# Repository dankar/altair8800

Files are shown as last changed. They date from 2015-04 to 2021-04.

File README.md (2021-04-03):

altair8800
==========

What is this?
-------------

What started as a Intel 8080 emulator turned into a Altair 8800 emulator with associated hardware for a front panel.

An updated version of this project is available at https://github.com/dankar/nanoaltair8800

Building
--------

The build for Arduino Uno is the most up to date. It should work to run "./build" and then "make && upload" in the arduino folder to compile and program.

arduino-mk is used by the makefile.

The code will look for certain files on the SD card. "88dskrom.bin" is a disk bootloader which will be loaded to offset 0xff00 in memory. "disk1.bin" and "disk2.bin" will be used by the 88-DCDD emulator and will act as disk 1 and disk 2 respectively.

Completeness
------------

Passes Kelly Smith test and cputest.com. Runs CP/M and all kinds of BASIC I could find. Altair DOS not working for some reason (complains about insufficient memory). Support for 88-DCDD. No tape or cassette.

There are probably still a few bugs that needs ironing out.

The performance is pretty poor. The emulator runs a couple of times slower than an original Altair 8800 which is a bit disappointing. It's of course also possible porting it to a faster MCU with more memory. Higher optimization levels will cause the code not to fit on an atmega328 but there are still code optimizations to be done. It is currently not possible to stop execution once started with the RUN/STOP switch. It's way too slow to check the front panel switches for each main loop.

Hardware
--------

A front panel has been designed and is available as a KiCad project under the PCB folder. The front panel is basically a bunch of shift registers for input from the switches and output to the LEDs, as well as a 23LC1024 SPI SRAM chip for memory and a MicroSD reader. Everything is attached on the SPI bus to the Arduino.

Known bugs
----------

The current hardware implementation has a bug in the MicroSD card holder-area. The pins are connected as they should be for a regular size SD card and not a MicroSD. If you want to use the panel with a MicroSD card you need to fix this.

Raspberry Pi
------------

The current code in the repo now supports running on Raspberry Pi instead of Arduino. This means that the MicroSD slot is not necessary any more, as well as the SRAM chip. The code runs faster on a Raspberry Pi as well. I would recommend this route for anyone interested in their own panel.

Todo
----

* Separate the Intel 8080 emulator and the Altair 8800 hardware emulation. E.g. make the port IO more abstract instead of Altair 8800 specific.
* Optimizations
* RUN/STOP switch enabled when running

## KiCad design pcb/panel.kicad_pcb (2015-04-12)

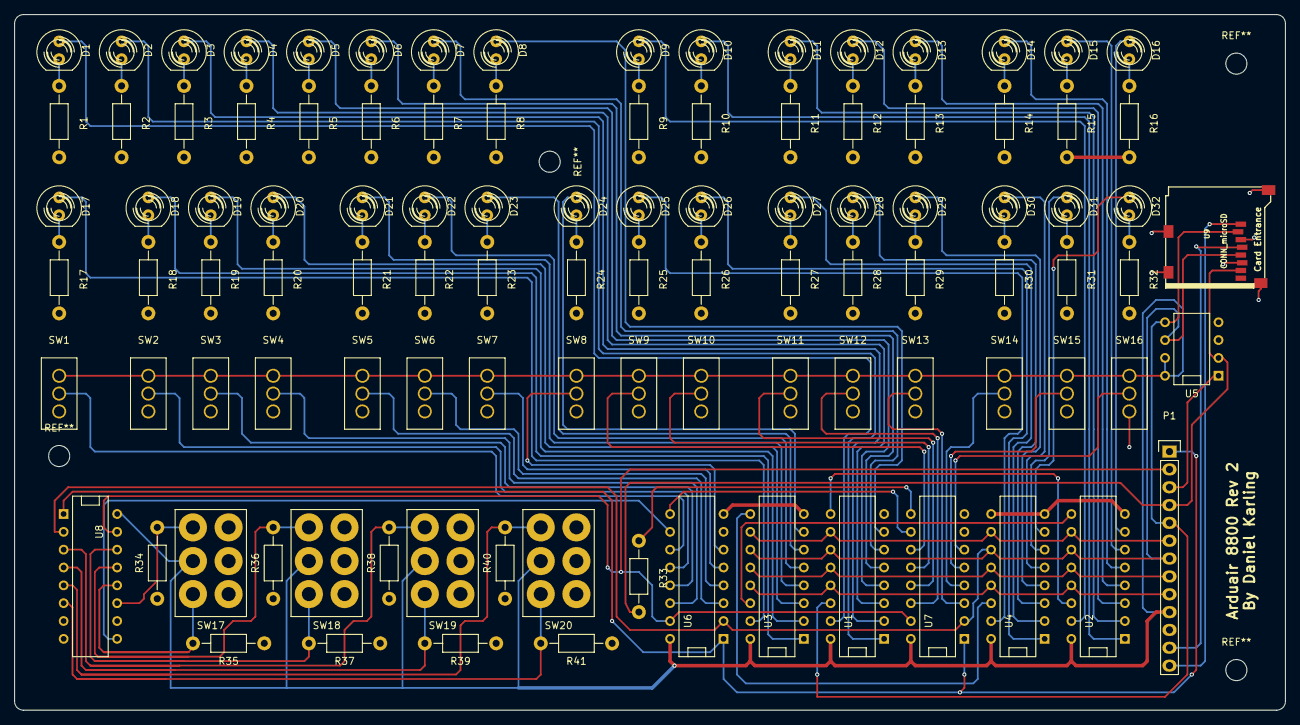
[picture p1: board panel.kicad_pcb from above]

Board: 2 copper layers, 181.0 x 99.1 mm, 103 parts (0 on the bottom side), 107 nets.

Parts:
D1, D2, D3, D4, D5, D6, D7, D8, D9, D10, D11, D12, D13, D14, D15, D16, D17, D18, D19, D20, D21, D22, D23, D24, D25, D26, D27, D28, D29, D30, D31, D32: LED; LED-5MM
P1: CONN_01X09; Pin_Header_Straight_1x13
R1, R2, R3, R4, R5, R6, R7, R8, R9, R10, R11, R12, R13, R14, R15, R16, R17, R18, R19, R20, R21, R22, R23, R24, R25, R26, R27, R28, R29, R30, R31, R32, R33: 220R; Resistor_Horizontal_RM10mm
R34, R35, R36, R37, R38, R39, R40, R41: 10K; Resistor_Horizontal_RM10mm
SW1, SW2, SW3, SW4, SW5, SW6, SW7, SW8, SW9, SW10, SW11, SW12, SW13, SW14, SW15, SW16: SWITCH_INV; SwitchOnOn
SW17, SW18, SW19, SW20: SP3T; SwitchOnOffOn
U1, U2, U3, U4: 74HC595; DIP-16__300
U5: 23LC1024; DIP-8__300
U6, U7, U8: 74LS165; DIP-16__300
U9: CONN_microSD; Memory_Card_microSD_3M_290805

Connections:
/CLK: P1.7, U1.11, U2.11, U3.11, U4.11, U5.6, U6.2, U7.2, U8.2, U9.5
/LA1: D1.1, U1.15
/LA2: D2.1, U1.1
/LA3: D3.1, U1.2
/LA4: D4.1, U1.3
/LA5: D5.1, U1.4
/LA6: D6.1, U1.5
/LA7: D7.1, U1.6
/LA8: D8.1, U1.7
/LB1: D9.1, U2.15
/LB2: D10.1, U2.1
/LB3: D11.1, U2.2
/LB4: D12.1, U2.3
/LB5: D13.1, U2.4
/LB6: D14.1, U2.5
/LB7: D15.1, U2.6
/LB8: D16.1, U2.7
/LC1: D17.1, U3.15
/LC2: D18.1, U3.1
/LC3: D19.1, U3.2
/LC4: D20.1, U3.3
/LC5: D21.1, U3.4
/LC6: D22.1, U3.5
/LC7: D23.1, U3.6
/LC8: D24.1, U3.7
/LD1: D25.1, U4.15
/LD2: D26.1, U4.1
/LD3: D27.1, U4.2
/LD4: D28.1, U4.3
/LD5: D29.1, U4.4
/LD6: D30.1, U4.5
/LD7: D31.1, U4.6
/LD8: D32.1, U4.7
/LEDSTORE: P1.8, U1.12, U2.12, U3.12, U4.12
/MEM_CS: P1.3, U5.1
/MISO: P1.4, R33.2, U5.2, U9.7
/MOSI: P1.5, U1.14, U5.5, U9.2
/MR: P1.6, U1.10, U2.10, U3.10, U4.10
/OE: P1.9, U1.13, U2.13, U3.13, U4.13
/SD_SC: P1.13, U9.1
/SWA1: SW1.2, U6.11
/SWA2: SW2.2, U6.12
/SWA3: SW3.2, U6.13
/SWA4: SW4.2, U6.14
/SWA5: SW5.2, U6.3
/SWA6: SW6.2, U6.4
/SWA7: SW7.2, U6.5
/SWA8: SW8.2, U6.6
/SWB1: SW9.2, U7.11
/SWB2: SW10.2, U7.12
/SWB3: SW11.2, U7.13
/SWB4: SW12.2, U7.14
/SWB5: SW13.2, U7.3
/SWB6: SW14.2, U7.4
/SWB7: SW15.2, U7.5
/SWB8: SW16.2, U7.6
/SWC1: R34.1, SW17.1, U8.11
/SWC2: R35.1, SW17.4, U8.12
/SWC3: R36.1, SW18.1, U8.13
/SWC4: R37.1, SW18.4, U8.14
/SWC5: R38.1, SW19.1, U8.3
/SWC6: R39.1, SW19.4, U8.4
/SWC7: R40.1, SW20.1, U8.5
/SWC8: R41.1, SW20.4, U8.6
/SWITCH_CS: P1.2, U6.15, U7.15, U8.15
/SWITCH_LOAD: P1.1, U6.1, U7.1, U8.1
/VCC33: P1.12, U9.4
GND: P1.11, R1.2, R2.2, R3.2, R4.2, R5.2, R6.2, R7.2, R8.2, R9.2, R10.2, R11.2, R12.2, R13.2, R14.2, R15.2, R16.2, R17.2, R18.2, R19.2, R20.2, R21.2, R22.2, R23.2, R24.2, R25.2, R26.2, R27.2, R28.2, R29.2, R30.2, R31.2, R32.2, R34.2, R35.2, R36.2, R37.2, R38.2, R39.2, R40.2, R41.2, SW1.1, SW2.1, SW3.1, SW4.1, SW5.1, SW6.1, SW7.1, SW8.1, SW9.1, SW10.1, SW11.1, SW12.1, SW13.1, SW14.1, SW15.1, SW16.1, U1.8, U2.8, U3.8, U4.8, U4.9, U5.3, U5.4, U6.7, U6.8, U7.7, U7.8, U8.7, U8.8, U8.10, U9.3, U9.6, U9.9
unnamed: D1.2, R1.1
unnamed: D2.2, R2.1
unnamed: D3.2, R3.1
unnamed: D4.2, R4.1
unnamed: D5.2, R5.1
unnamed: D6.2, R6.1
unnamed: D7.2, R7.1
unnamed: D8.2, R8.1
unnamed: D9.2, R9.1
unnamed: D10.2, R10.1
unnamed: D11.2, R11.1
unnamed: D12.2, R12.1
unnamed: D13.2, R13.1
unnamed: D14.2, R14.1
unnamed: D15.2, R15.1
unnamed: D16.2, R16.1
unnamed: D17.2, R17.1
unnamed: D18.2, R18.1
unnamed: D19.2, R19.1
unnamed: D20.2, R20.1
unnamed: D21.2, R21.1
unnamed: D22.2, R22.1
unnamed: D23.2, R23.1
unnamed: D24.2, R24.1
unnamed: D25.2, R25.1
unnamed: D26.2, R26.1
unnamed: D27.2, R27.1
unnamed: D28.2, R28.1
unnamed: D29.2, R29.1
unnamed: D30.2, R30.1
unnamed: D31.2, R31.1
unnamed: D32.2, R32.1
unnamed: R33.1, U7.9
unnamed: U1.9, U2.14
unnamed: U2.9, U3.14
unnamed: U3.9, U4.14
unnamed: U6.9, U7.10
unnamed: U6.10, U8.9
VCC: P1.10, SW1.3, SW2.3, SW3.3, SW4.3, SW5.3, SW6.3, SW7.3, SW8.3, SW9.3, SW10.3, SW11.3, SW12.3, SW13.3, SW14.3, SW15.3, SW16.3, SW17.3, SW18.3, SW19.3, SW20.3, U1.16, U2.16, U3.16, U4.16, U5.7, U5.8, U6.16, U7.16, U8.16

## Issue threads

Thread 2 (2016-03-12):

Wiring for MicroSD connector is incorrect

dankar, 2016-03-12:
The MicroSD slot is wired to regular SD card. This is not correct and should be fixed.

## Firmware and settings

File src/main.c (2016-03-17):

#include <stdio.h>
#include <stdlib.h>
#include "intel8080.h"
#include "88dcdd.h"
#ifdef WIN32
	#include <Windows.h>
	#include <WinSock.h>
#else
	// socket
	#include <sys/types.h>
	#include <sys/socket.h>
	#include <netinet/in.h>
	#include <netinet/ip.h>
	#include <sys/ioctl.h>
	#include <fcntl.h>

	// strcat
	#include <string.h>
	#include "pi_panel.h"
	#include <wiringPi.h>
#endif

int sock;
int client_sock;

void dump_regs(intel8080_t *cpu)
{
	printf("%04x\t%02x\t%04x\tC: %02x\tD: %02x\tE: %02x\n", cpu->address_bus, cpu->data_bus, cpu->registers.pc, cpu->registers.c, cpu->registers.d, cpu->registers.e);
}

#ifdef WIN32
uint8_t key_states[256];

uint8_t get_key(uint8_t code)
{
	uint8_t ret_val = 0;

	if(GetAsyncKeyState(code))
	{
		if(!key_states[code])
			ret_val = 1;

		key_states[code] = 1;
	}
	else
	{
		key_states[code] = 0;
	}

	return ret_val;
}
#endif

uint8_t term_in()
{
	uint8_t b;

	if(recv(client_sock, (char*)&b, 1, 0) != 1)
	{
		return 0;
	}
	else
	{
		return b;
	}
}

void term_out(uint8_t b)
{
	b = b & 0x7f;
	send(client_sock, (char*)&b, 1, 0);
}

uint8_t memory[64*1024];
uint8_t cmd_switches;
uint16_t bus_switches;

void load_file(intel8080_t *cpu)
{
	size_t size = 0;
	FILE* fp = fopen("software/input.com", "rb");

	fseek(fp, 0, SEEK_END);
	size = ftell(fp);
	fseek(fp, 0, SEEK_SET);
	fread(&memory[0x100], 1, size, fp);
	fclose(fp);
}

const char *byte_to_binary(int x)
{
	int z;
    static char b[9];
    b[0] = '\0';

    for (z = 128; z > 0; z >>= 1)
    {
        strcat(b, ((x & z) == z) ? "1" : "0");
    }

    return b;
}


void load_mem_file(const char* filename, size_t offset)
{
	size_t size;
	FILE* fp = fopen(filename, "rb");
	fseek(fp, 0, SEEK_END);
	size = ftell(fp);
	fseek(fp, 0, SEEK_SET);
	fread(&memory[offset], 1, size, fp);
	fclose(fp);
}

uint8_t sense()
{
	return bus_switches >> 8;
}

void load_memory()
{
        load_mem_file("software/ROMs/DBL.bin", 0xff00);
        load_mem_file("software/ROMs/8K Basic/8kBas_e0.bin", 0xe000);
        load_mem_file("software/ROMs/8K Basic/8kBas_e8.bin", 0xe800);
        load_mem_file("software/ROMs/8K Basic/8kBas_f0.bin", 0xf000);
        load_mem_file("software/ROMs/8K Basic/8kBas_f8.bin", 0xf800);
}

int main(int argc, char *argv[])
{
	uint32_t counter = 0;
	unsigned long ok = 1;
	char yes = 1;
	struct sockaddr_in listen_addr;
	struct sockaddr client_addr;
	int sock_size;
	uint16_t breakpoint = 0x0;
	disk_controller_t disk_controller;
	intel8080_t cpu;

	rpi_init();

#ifdef WIN32
	WSADATA wsaData;

	if (WSAStartup(MAKEWORD(1, 1), &wsaData) != 0)
	{
		printf("Could not start WSA\n");
		return 1;
	}

	memset(key_states, 0, 256);

#endif

	memset(memory, 0, 64*1024);
	sock = socket(AF_INET, SOCK_STREAM, 0);

#ifdef WIN32
	ioctlsocket(sock, FIONBIO, &ok);
#endif

	setsockopt(sock, SOL_SOCKET, SO_LINGER, &yes, sizeof(char));
	setsockopt(sock, SOL_SOCKET, SO_REUSEADDR, &yes, sizeof(int));

	listen_addr.sin_family = AF_INET;
	listen_addr.sin_addr.s_addr = INADDR_ANY;
	listen_addr.sin_port = htons(8800);
	memset(&(listen_addr.sin_zero), '\0', 8);

	if(bind(sock, (struct sockaddr*)&listen_addr, sizeof(listen_addr)) == -1)
	{
		printf("Could not bind\n");
	}

	printf("Waiting for terminal on port 8800...\n");

	do
	{
		listen(sock, 1);
		sock_size = sizeof(client_addr);
		client_sock = accept(sock, &client_addr, &sock_size);
	}while(client_sock == -1);

#ifndef WIN32
	fcntl(client_sock, F_SETFL, O_NONBLOCK);
#endif

	printf("Got connection. %d\n", client_sock);

	disk_controller.disk_function = disk_function;
	disk_controller.disk_select = disk_select;
	disk_controller.disk_status = disk_status;
	disk_controller.read = read;
	disk_controller.write = write;
	disk_controller.sector = sector;

	i8080_reset(&cpu, term_in, term_out, sense, &disk_controller);

	load_memory();

	// Mount diskette 1 (CP/M OS) and 2 (Tools)
	disk_drive.disk1.fp = fopen("software/CPM 2.2/cpm63k.dsk", "r+b");
	//disk_drive.disk1.fp = fopen("software/BASIC/Floppy Disk/Disk Basic Ver 300-5-F.dsk", "r+b");
	disk_drive.disk2.fp = fopen("software/CPM 2.2/games.dsk", "r+b");
	//disk_drive.disk2.fp = fopen("software/BASIC/Floppy Disk/Games on 300-5-F.dsk", "r+b");
	disk_drive.nodisk.status = 0xff;

	i8080_examine(&cpu, 0x0000); // ff00 loads from disk, e000 loads basic

	uint8_t cmd_state;
	uint8_t last_cmd_state = 0;
	uint8_t mode = STOP;
	uint32_t last_debounce = 0;

	uint32_t cycle_counter = 0;

	while(1)
	{
		if(mode == RUN)
		{
			i8080_cycle(&cpu);
			cycle_counter++;
			if(cycle_counter % 10 == 0)
				read_write_panel(0, cpu.data_bus, cpu.address_bus, &bus_switches, &cmd_switches, 1);
		}
		else
		{
			read_write_panel(0, cpu.data_bus, cpu.address_bus, &bus_switches, &cmd_switches, 1);
		}

		if(cmd_switches != last_cmd_state)
		{
			last_debounce = millis();
		}

		if((millis() - last_debounce) > 50)
		{
			if(cmd_switches != cmd_state)
			{
				cmd_state = cmd_switches;
				if(mode == STOP)
				{
					if(cmd_switches & STOP)
					{
						load_memory();
						i8080_examine(&cpu, 0);
					}
					if(cmd_switches & SINGLE_STEP)
					{
						i8080_cycle(&cpu);
					}
					if(cmd_switches & EXAMINE)
					{
						printf("Examine %x\n", bus_switches);
						i8080_examine(&cpu, bus_switches);
					}
					if(cmd_switches & EXAMINE_NEXT)
					{
						i8080_examine_next(&cpu);
					}
					if(cmd_switches & DEPOSIT)
					{
						i8080_deposit(&cpu, bus_switches & 0xff);
					}
					if(cmd_switches & DEPOSIT_NEXT)
					{
						i8080_deposit(&cpu, bus_switches & 0xff);
					}
					if(cmd_switches & RUN_CMD)
					{
						mode = RUN;
					}
				}
				if(mode == RUN)
				{
					if(cmd_switches & STOP_CMD)
					{
						mode = STOP;
					}
				}
			}
		}
		last_cmd_state = cmd_switches;
	}

	return 0;
}

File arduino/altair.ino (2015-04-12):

#include <SPI.h>
#include <SdFat.h>
#include "intel8080.h"
#include "88dcdd.h"
#include "memory.h"
#include "pins.h"
#include "panel.h"

SdFat SD;

intel8080_t cpu;
disk_controller_t disk_controller;
uint32_t start_time = 0;
uint32_t end_time = 0;
uint32_t counter = 0;

void term_out(uint8_t c)
{
	Serial.write(c & 0x7f);
}

uint8_t term_in()
{
	if(Serial.available())
	{
		return Serial.read();
	}
	else
	{
		return 0;
	}
}

void load_to_mem(const char *filename, size_t offset)
{
	uint16_t counter = 0;
	File rom = SD.open(filename);

	if(!rom)
	{
		Serial.print("F:");
		Serial.println(filename);
		return;
	}

	rom.seek(0);

	while(rom.available())
	{
		write8(counter++ + offset, rom.read());
	}

	rom.close();
}

void setup()
{
	Serial.begin(115200);

	pinMode(SWITCHES_LOAD, OUTPUT);
	pinMode(SWITCHES_CS, OUTPUT);

	digitalWrite(SWITCHES_LOAD, HIGH);
	digitalWrite(SWITCHES_CS, HIGH);

	pinMode(MEMORY_CS, OUTPUT);
	digitalWrite(MEMORY_CS, HIGH);

	pinMode(LEDS_OE, OUTPUT);

	digitalWrite(LEDS_OE, LOW);

	pinMode(LEDS_LATCH, OUTPUT);
	digitalWrite(LEDS_LATCH, HIGH);

	if(!SD.begin(SD_CS, SPI_CLOCK_DIV2))
	{
		Serial.println("SD");
		return;
	}
	SPI.setClockDivider(SPI_CLOCK_DIV2);

	digitalWrite(MEMORY_CS, LOW);
	SPI.transfer(1); // Write mode register
	SPI.transfer(0); // Byte mode
	digitalWrite(MEMORY_CS, HIGH);

	load_to_mem("88dskrom.bin", 0xff00);

	disk_controller.disk_select = disk_select;
	disk_controller.disk_status = disk_status;
	disk_controller.disk_function = disk_function;
	disk_controller.sector = sector;
	disk_controller.write = write;
	disk_controller.read = read;

	memset(&disk_drive, 0, sizeof(disks));
	
	disk_drive.disk1.fp = SD.open("disk1.dsk", FILE_WRITE);
	disk_drive.disk2.fp = SD.open("disk2.dsk", FILE_WRITE);
	if(!disk_drive.disk2.fp || !disk_drive.disk1.fp)
		Serial.println("D");

	disk_drive.nodisk.status = 0xff;

	i8080_reset(&cpu, term_in, term_out, sense_switches, &disk_controller);
	i8080_examine(&cpu, 0x0000);
}

uint8_t mode = STOP; 

uint8_t cmd_state = 0;
uint8_t last_cmd_state = 0;
long last_debounce = 0;

void loop()
{
	uint16_t address;
	uint8_t cmd;

	if(mode == STOP)
	{
		read_switches(&address, &cmd);
	
		if(cmd != last_cmd_state)
		{
			last_debounce = millis();
		}
	
		if((millis() - last_debounce) > 50)
		{
			if(cmd != cmd_state)
			{
				cmd_state = cmd;
				if(cmd & SINGLE_STEP)
				{
					i8080_cycle(&cpu);
				}
				if(cmd & EXAMINE)
				{
					i8080_examine(&cpu, address);
				}
				if(cmd & EXAMINE_NEXT)
				{
					i8080_examine_next(&cpu);
				}
				if(cmd & DEPOSIT)
				{
					i8080_deposit(&cpu, address & 0xff);
				}
				if(cmd & DEPOSIT_NEXT)
				{
					i8080_deposit_next(&cpu, address & 0xff);
				}
				if(cmd & RUN_CMD)
				{
					mode = RUN;
				}
			}
		}
	
		last_cmd_state = cmd;
	}
	else
	{
		i8080_cycle(&cpu);
	}
}

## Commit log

2014-12-16 Non blocking socket on linux
2014-12-16 Added ifdef on socket blocking
2014-12-17 New .gitignore for the arduino folder since we need to copy files
2014-12-17 Added arduino stuff
2014-12-18 Arduino build now runs CP/M
2015-01-05 Changed arduino code to use 23LC1024 SRAM chip instead of SD card for memory.
2015-01-05 Added build script for arduino
2015-01-05 Fixed 2sio so that ladder.com and zork works
    [main.c]
2015-01-05 Added optional debug outputs for disk driver and fixed issue with integer overflow wheen changing tracks.
    [88dcdd.c, altair.ino]
2015-01-06 Fixed build for x86
    [88dcdd.c, altair.ino, main.c]
2015-04-12 Added schematics
    [panel.kicad_pcb, panel.sch, panel_old.kicad_pcb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]
2015-04-12 Changed value of R33 to 220 Ohms. New value found through testing.
    [panel.kicad_pcb, panel.sch]
2016-03-12 Added support for panel connected to Raspberry Pi. Regular Linux builds now target Raspberry Pi.
2016-03-17 Final parts of panel support on Raspberry Pi.
2016-11-11 Update README.md
    Added the current status of the project to readme.
